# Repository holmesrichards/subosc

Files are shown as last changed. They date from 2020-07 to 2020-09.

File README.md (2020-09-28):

# subosc
Kosmo or Eurorack format sub oscillator 

Circuit design by Analog Lab Swiss (Carmelo Azarello).

PCB and Kosmo front panel design by Rich Holmes.

Zener diodes on the sub oscillator output are optional and probably don't really do anything. They can be omitted. Zeners on the clock div outputs limit those outputs to 5.1V and should be included.

Kosmo panel is for a dual sub oscillator module. It uses two copies of the PCB. In one of the two, omit the Clock Div output jacks, resistors, and diodes. Also omit the power header, series Schottky diode, and 10uF capacitor; instead run wires from the +12V and ground wire pads on the first board to the corresponding pads on the second.

A version was built and tested and found to work once I corrected my mistake (by a factor of 1000) in the value of C1. That value has been updated here, so all should be good. (I used a ceramic cap but have specified poly box. Either should be okay but poly may be better.)

For Azarello's version this is taken from, see https://www.facebook.com/photo.php?fbid=10158135029647692&set=pcb.10157466790532753&type=3&theater . Some minor differences:
* Original was battery powered, with 100 µF cap to ground
* Original C1 was specified as ceramic
* Original had 47 µF cap on input, described as optional
* Original used 2n3904 for Q1

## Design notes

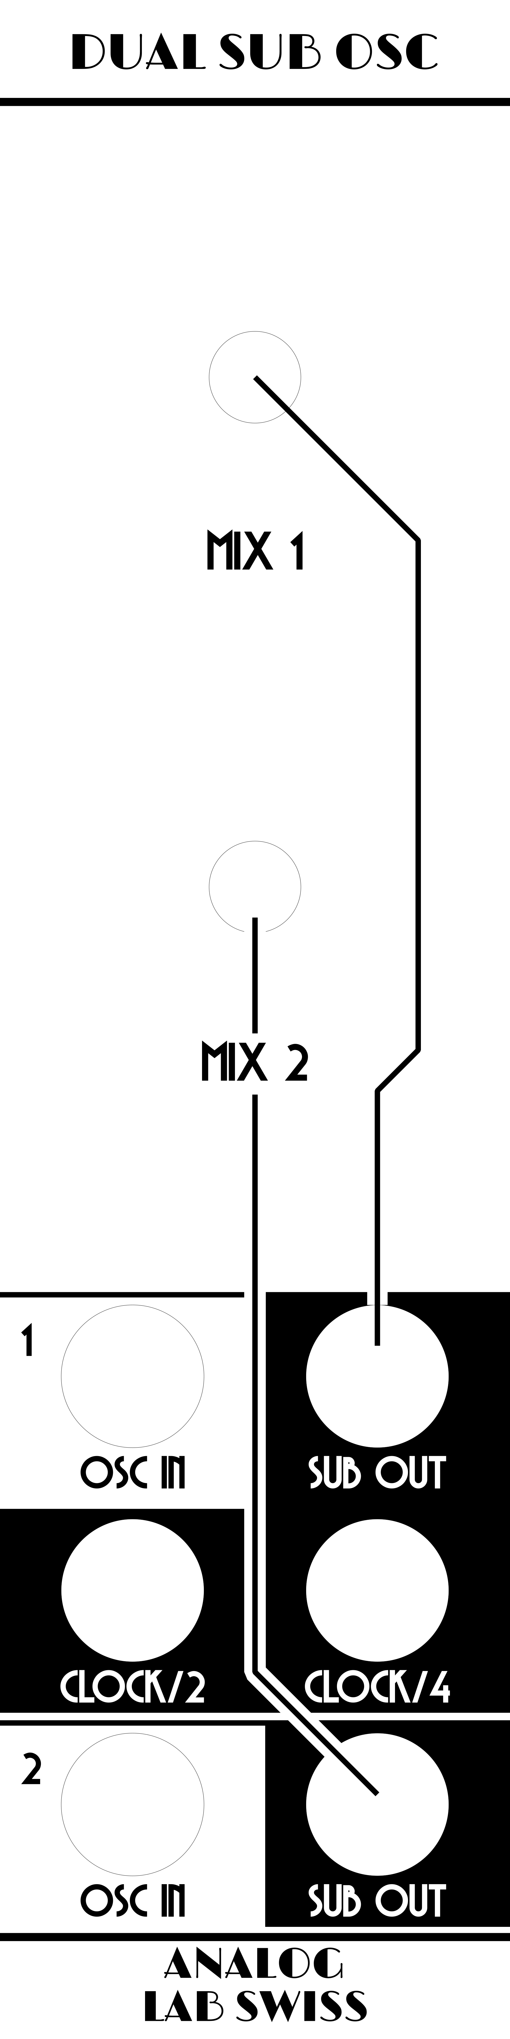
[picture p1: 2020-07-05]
Panel/sub osc art.png

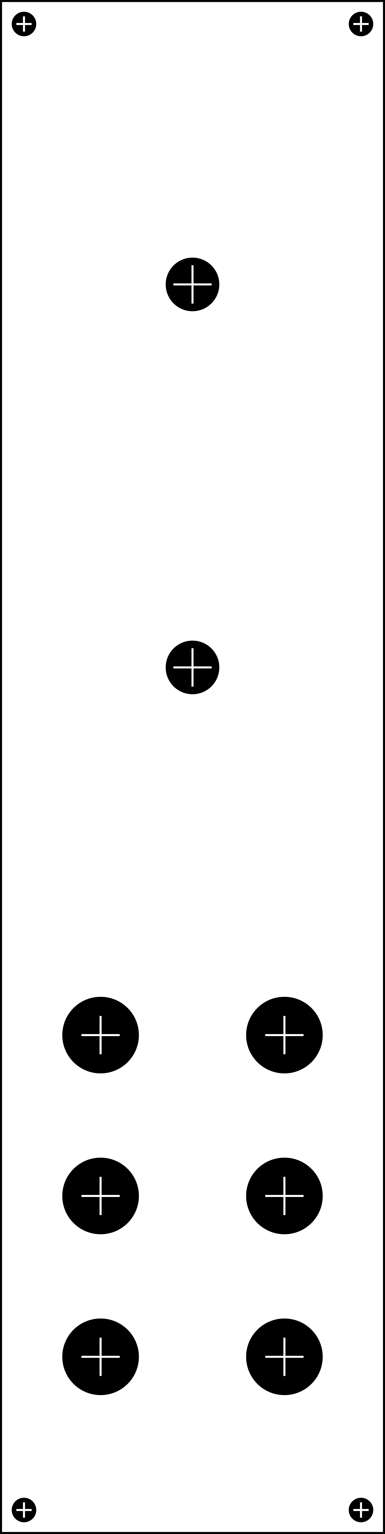
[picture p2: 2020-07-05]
Panel/sub osc holes.png

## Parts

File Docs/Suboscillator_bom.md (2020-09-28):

# Suboscillator BOM

Tue 01 Sep 2020 08:36:15 AM EDT

Generated from schematic by Eeschema 5.1.6-c6e7f7d~87~ubuntu20.04.1

Parts for one unit. Parts marked (*) are not used for second unit in dual module. Parts marked (**) are optional for both units.

**Component Count:** 39

| Value | Qty | Part | Description | Vendor |
| ----- | --- | ---- | --- | --- |
| C1 | 1 | 10nF | Unpolarized capacitor |  |
| C2 | 1 | 10uF (*) | Polarized capacitor |  |
| C3 | 1 | 0.1uF | Unpolarized capacitor |  |
| C4 | 1 | 47uF | Polarized capacitor |  |
| D1 | 1 | 1N4148 | 100V 0.15A standard switching diode, DO-35 |  |
| D2 | 1 | 1n5817 (*) | Schottky diode |  |
| D3, D4 | 2 | 1n4733 (*) | Zener diode |  |
| D5, D6 | 2 | 1n4733 (**) | Zener diode |  |
| J1, J5 | 2 | 2 PIN HDR | 2 pin Molex header 2.54 mm |  |
| J2 | 1 | EURO_PWR_2x5 (*) |  |  |
| J3 | 1 | 3 PIN HDR | 3 pin Molex header 2.54 mm |  |
| J4, J6 | 2 | 2 PIN HDR (*) | 2 pin Molex header 2.54 mm |  |
| J9, J13 | 2 | AudioJack2 | Audio Jack, 2 Poles (Mono / TS) |  |
| J10, J14 | 2 | 2 PIN CONN | 2 pin Molex connector 2.54 mm |  |
| J11, J15 | 2 | AudioJack2 (*) | Audio Jack, 2 Poles (Mono / TS) |  |
| J12, J16 | 2 | 2 PIN CONN (*) | 2 pin Molex connector 2.54 mm |  |
| J17 | 1 | 3 PIN CONN | 3 pin Molex connector 2.54 mm |  |
| Q1 | 1 | BC547 | 0.1A Ic, 45V Vce, Small Signal NPN Transistor, TO-92 |  |
| R1, R4, R8 | 3 | 100k | Resistor |  |
| R2 | 1 | 10k | Resistor |  |
| R3 | 1 | 3.3k | Resistor |  |
| R5 | 1 | 56k | Resistor |  |
| R6, R7 | 2 | 1k (*) | Resistor |  |
| R9 | 1 | 1k | Resistor |  |
| RV1 | 1 | B100k | Potentiometer |  |
| U1 | 1 | 4013 | Dual D  FlipFlop, Set & reset |  |

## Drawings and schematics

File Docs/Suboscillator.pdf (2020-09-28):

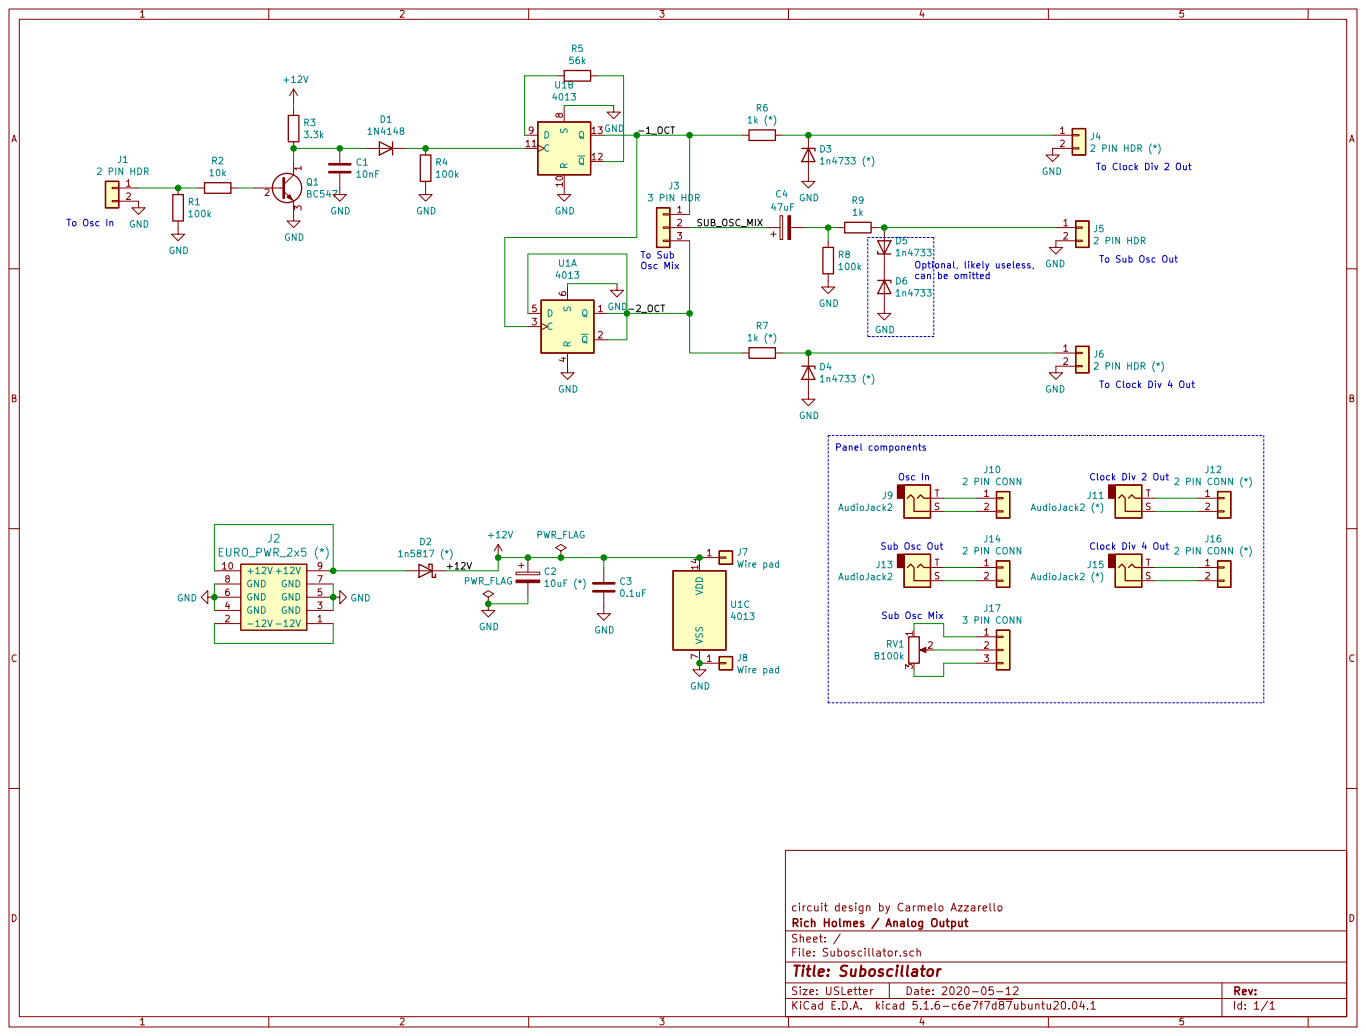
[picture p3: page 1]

circuit design by Carmelo Azzarello
Id: 1/1 Title: Suboscillator File: Suboscillator.sch Sheet: / Rich Holmes / Analog Output

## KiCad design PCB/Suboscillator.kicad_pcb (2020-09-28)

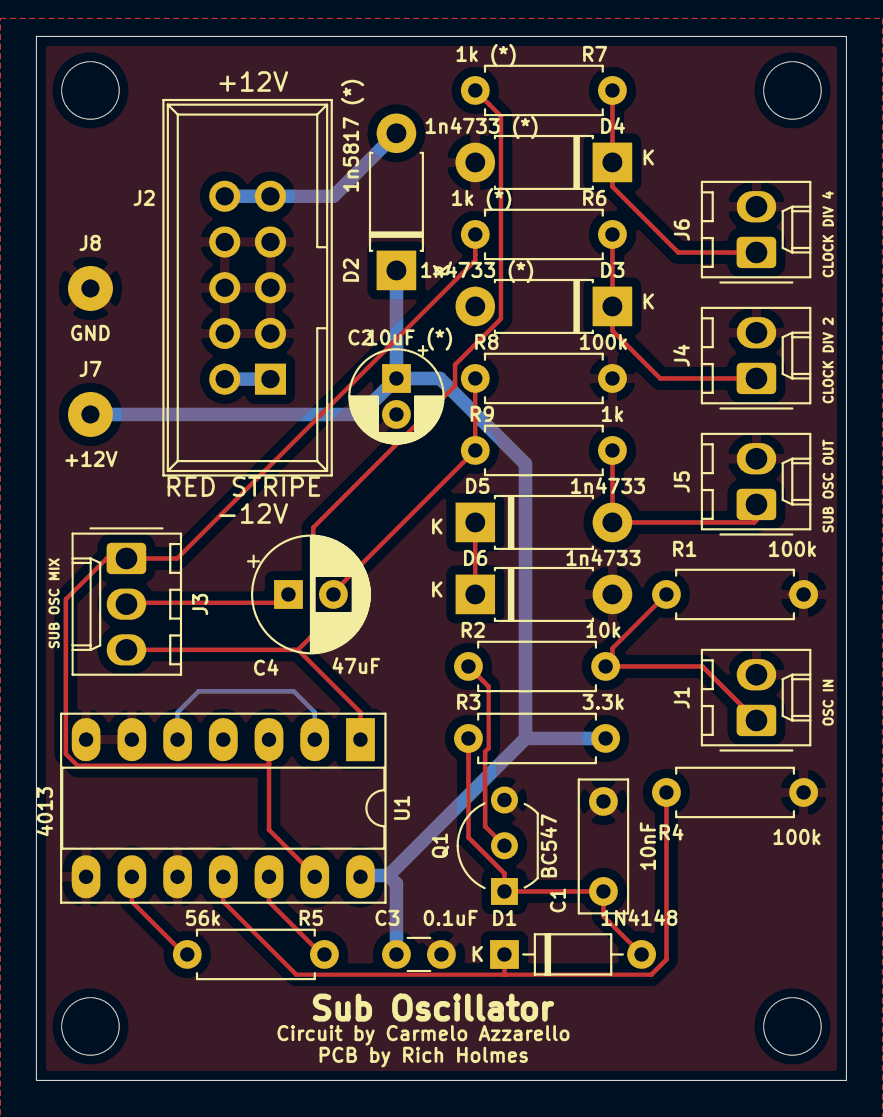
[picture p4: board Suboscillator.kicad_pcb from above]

Board: 2 copper layers, 45.0 x 58.0 mm, 29 parts (0 on the bottom side), 19 nets.

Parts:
C1: 10nF; C_Rect_L7.2mm_W2.5mm_P5.00mm_FKS2_FKP2_MKS2_MKP2
C2: 10uF (*); CP_Radial_D5.0mm_P2.00mm
C3: 0.1uF; C_Disc_D3.0mm_W1.6mm_P2.50mm
C4: 47uF; CP_Radial_D6.3mm_P2.50mm
D1: 1N4148; D_DO-35_SOD27_P7.62mm_Horizontal
D2: 1n5817 (*); D_DO-41_SOD81_P7.62mm_Horizontal
D3, D4: 1n4733 (*); D_DO-41_SOD81_P7.62mm_Horizontal
D5, D6: 1n4733; D_DO-41_SOD81_P7.62mm_Horizontal
J1, J5: 2 PIN HDR; Molex_KK-254_AE-6410-02A_1x02_P2.54mm_Vertical
J2: EURO_PWR_2x5 (*); Power_Header
J3: 3 PIN HDR; Molex_KK-254_AE-6410-03A_1x03_P2.54mm_Vertical
J4, J6: 2 PIN HDR (*); Molex_KK-254_AE-6410-02A_1x02_P2.54mm_Vertical
J7, J8: Wire pad; SolderWirePad_1x01_Drill1mm
Q1: BC547; TO-92_Inline_Wide
R1, R4, R8: 100k; R_Axial_DIN0207_L6.3mm_D2.5mm_P7.62mm_Horizontal
R2: 10k; R_Axial_DIN0207_L6.3mm_D2.5mm_P7.62mm_Horizontal
R3: 3.3k; R_Axial_DIN0207_L6.3mm_D2.5mm_P7.62mm_Horizontal
R5: 56k; R_Axial_DIN0207_L6.3mm_D2.5mm_P7.62mm_Horizontal
R6, R7: 1k (*); R_Axial_DIN0207_L6.3mm_D2.5mm_P7.62mm_Horizontal
R9: 1k; R_Axial_DIN0207_L6.3mm_D2.5mm_P7.62mm_Horizontal
U1: 4013; DIP-14_W7.62mm_Socket_LongPads

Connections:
+12V: C2.1, C3.1, D2.1, J7.1, R3.1, U1.14
/-1_OCT: J3.1, R6.2, U1.3, U1.13
/-2_OCT: J3.3, R7.2, U1.1
/SUB_OSC_MIX: C4.1, J3.2
GND: C1.2, C2.2, C3.2, D3.2, D4.2, D6.2, J1.2, J2.3, J2.4, J2.5, J2.6, J2.7, J2.8, J4.2, J5.2, J6.2, J8.1, Q1.3, R1.2, R4.2, R8.2, U1.6, U1.7, U1.8, U1.10
unnamed: C1.1, D1.2, Q1.1, R3.2
unnamed: C4.2, R8.1, R9.2
unnamed: D1.1, R4.1, U1.11
unnamed: D2.2, J2.9, J2.10
unnamed: D3.1, J4.1, R6.1
unnamed: D4.1, J6.1, R7.1
unnamed: D5.1, D6.1
unnamed: D5.2, J5.1, R9.1
unnamed: J1.1, R1.1, R2.2
unnamed: J2.1, J2.2
unnamed: Q1.2, R2.1
unnamed: R5.1, U1.12
unnamed: R5.2, U1.9
unnamed: U1.2, U1.5

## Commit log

2020-07-05 Initial version
    [Suboscillator-B_Cu.gbr, Suboscillator-B_Mask.gbr, Suboscillator-B_Paste.gbr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]
2020-07-05 rm older version
    [Suboscillator_older.kicad_pcb, Suboscillator_older.sch]
2020-07-05 rm unused footprint library
2020-07-05 Add panel components
    [Suboscillator.kicad_pcb, Suboscillator.sch]
2020-07-06 Comments in schematic and README
    [Suboscillator.kicad_pcb, Suboscillator.sch]
2020-09-01 Schematics cleanup
    [Suboscillator.sch]
2020-09-27 Schematic pdf, footprint, and 10nF, 10uF, what's the difference?
    [Suboscillator.kicad_pcb, Suboscillator.sch]
2020-09-28 Correct C1
    [Suboscillator-B_Cu.gbr, Suboscillator-B_Mask.gbr, Suboscillator-B_Paste.gbr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]
2020-09-28 C1 disc to box
    [Suboscillator.sch]
2021-01-02 Footprints updated
